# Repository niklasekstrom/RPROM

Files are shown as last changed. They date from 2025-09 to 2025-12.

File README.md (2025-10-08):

# RPROM

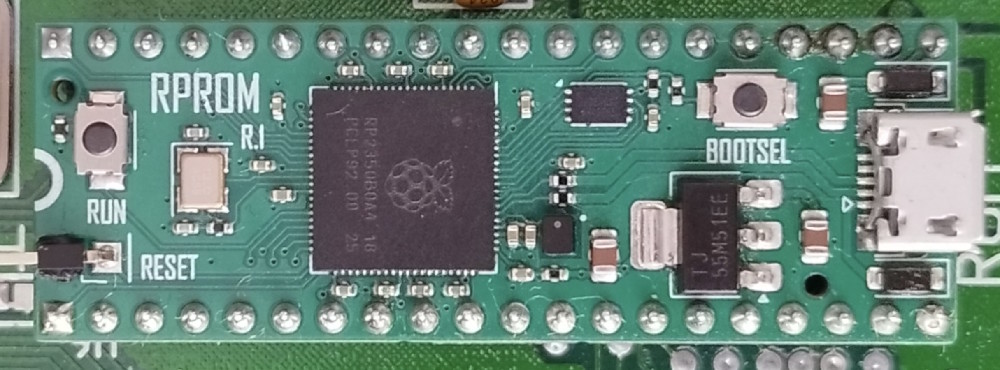
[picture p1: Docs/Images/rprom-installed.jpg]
RPROM rendered


RPROM is a ROM emulator for 16 bit Amiga computers (A500, A600, A2000) based on
the RP2350B microcontroller. RPROM was designed in collaboration by
[Niklas Ekström](https://github.com/niklasekstrom/) and
[Per Bengtsson](https://github.com/RetroNynjah).

The RPROM board has a 4 MB SPI flash memory. Each ROM image is 512 kB in size,
and therefore the 4 MB is divided into eight *slots* of 512 kB each. The first
slot is dedicated to store code and configuration data for the RP2350B. The
seven remaining slots are used to store ROM images.

ROM images can be written to flash memory either via USB, or directly from the
Amiga using a program called `RPROM`. This `RPROM` program is also used to
switch which slot is the *active slot*.

This repository contains the [hardware](Hardware), [firmware](Firmware) and
[software](Software) for RPROM. The design is intended to be easily
understandable and hackable. For example, the firmware is built from a single,
roughly 300 lines long, [source code file](Firmware/rprom.c).

## The RPROM command

`RPROM` is a CLI command that runs on the Amiga. It has the following
subcommands:

- `RPROM status` prints status information about the device
- `RPROM switch <slot>` switches the active slot and reboots the Amiga
- `RPROM write <slot> <image>` writes the content of file `<image>` to
slot `<slot>`
- `RPROM read <slot> <image>` reads the content of slot `<slot>` and saves it
to file `<image>`
- `RPROM erase <slot>` erases slot `<slot>`

Note that ROM images should *not* be byte swapped.

## Programming using USB

Both the firmware and ROM images can be programmed from a PC using USB.
Programming is done using the `picotool` program, which can be downloaded from
https://github.com/raspberrypi/pico-sdk-tools/releases. The RP2350B
microcontroller needs to first be in download mode. To put the RP2350B in
download mode, hold down the BOOTSEL button on the board, and then click the
RUN button. The microcontroller should show up as a USB drive on your PC.

To program the firmware, run `picotool load rprom.uf2`.

To write a ROM image to a slot, run `picotool load <image> -t bin -o <addr>`,
where `<addr>` depends on the slot:

- slot 1: `0x10080000`
- slot 2: `0x10100000`
- slot 3: `0x10180000`
- slot 4: `0x10200000`
- slot 5: `0x10280000`
- slot 6: `0x10300000`
- slot 7: `0x10380000`

## License

This design is free for non-comercial use. The designers take no responsibility
for if it doesn't work or if it causes damage to your equipment. If you want to
build boards to sell then you need to first ask for approval from the designers.

## Bill of materials (BOM)

| References | Value | Footprint | LCSC Part | Quantity |
|---|---|---|---|---|
| C2, C8, C11, C12, C13, C14, C15, C16, C17, C18, C20, C21 | 100n | C_0402_1005Metric | C1525 | 12 |
| C1, C5, C19 | 10u | C_0805_2012Metric | C15850 | 3 |
| C3, C4 | 15p | C_0402_1005Metric | C1548 | 2 |
| C6, C7, C9, C10 | 4.7u | C_0402_1005Metric | C23733 | 4 |
| R2, R4, R6 | 1k | R_0402_1005Metric | C11702 | 3 |
| R7, R8 | 27 | R_0402_1005Metric | C25092 | 2 |
| R1 | 10k | R_0402_1005Metric | C25744 | 1 |
| R3 | 33 | R_0402_1005Metric | C25105 | 1 |
| L1 | 3.3u | L_pol_2016 | C42411119 | 1 |
| D1, D2 | B5819W_SL | D_SOD-123 | C8598 | 2 |
| U1 | RP2350_80QFN | RP2350-QFN-80-1EP_10x10_P0.4mm_EP3.4x3.4mm | C42415655 | 1 |
| U2 | TLV1117-33 | SOT-223-3_TabPin2 | C15578 | 1 |
| Y1 | ABM8-272-T3 | Crystal_SMD_3225-4Pin_3.2x2.5mm | C20625731 | 1 |
| SW1, SW2 | SW_Push | SW_SPST_TS-1088 | C720477 | 2 |
| IC1 | W25Q32RVXHJQ *or* ZD25WQ32CEIGR | Winbond_USON-8-1EP_3x2mm_P0.5mm_EP0.2x1.6mm | C5258281 | 1 |
| J1 | USB_B_Micro | USB_Micro-B_Amphenol_10103594-0001LF_Horizontal | C428495 | 1 |
| J2, J3 | Conn_01x20 | PinHeader_1x20_P2.54mm_Vertical | - | 2 |
| J4 | Conn_01x01 | PinHeader_1x01_P2.54mm_Horizontal | - | 1 |

## Building

The hardware can be cheaply built by [JLCPCB](https://jlcpcb.com/) using
Economic PCBA. Components should be assembled only on the top side, and select
that tooling holes are "Added by Customer".

Please pay attention to the orientation of the components if ordering assembly
from JLCPCB. Especially pay attention to the orientation of coil L1. When
uploading the component placement file to JLCPCB I had to manually fix the
orientation of L1 regardless of what the component placement file specified.

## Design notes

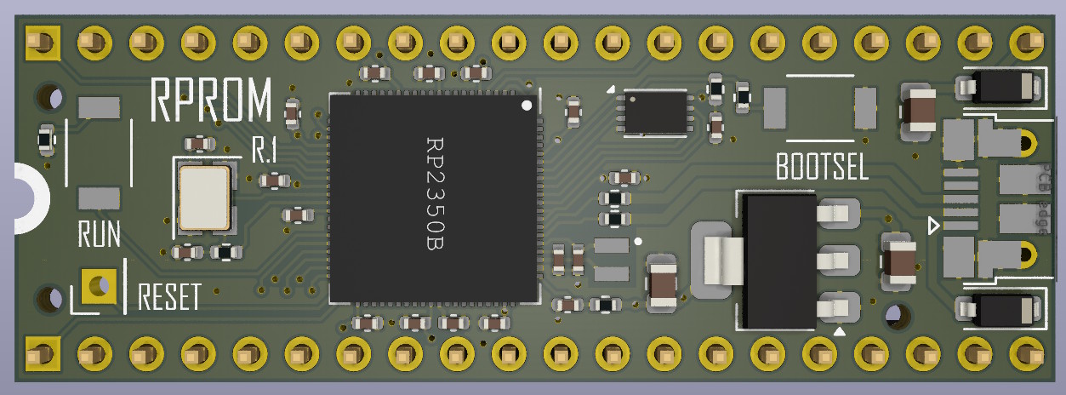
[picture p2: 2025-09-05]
Docs/Images/rprom-rendered.jpg

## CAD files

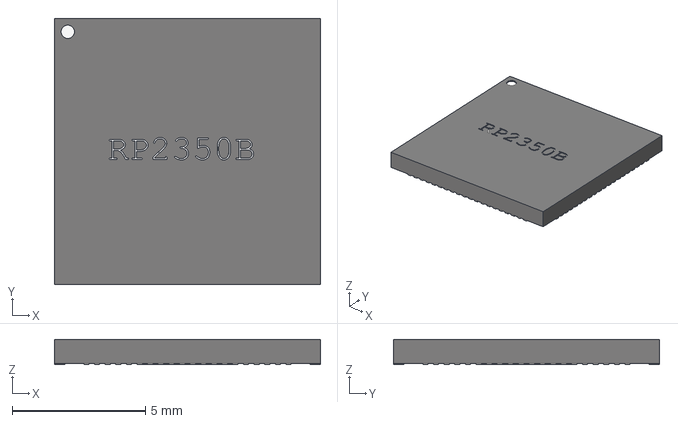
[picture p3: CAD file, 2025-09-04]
Hardware/KiCad/RP2350_QFN80.step
10.0 x 10.0 x 0.95 mm

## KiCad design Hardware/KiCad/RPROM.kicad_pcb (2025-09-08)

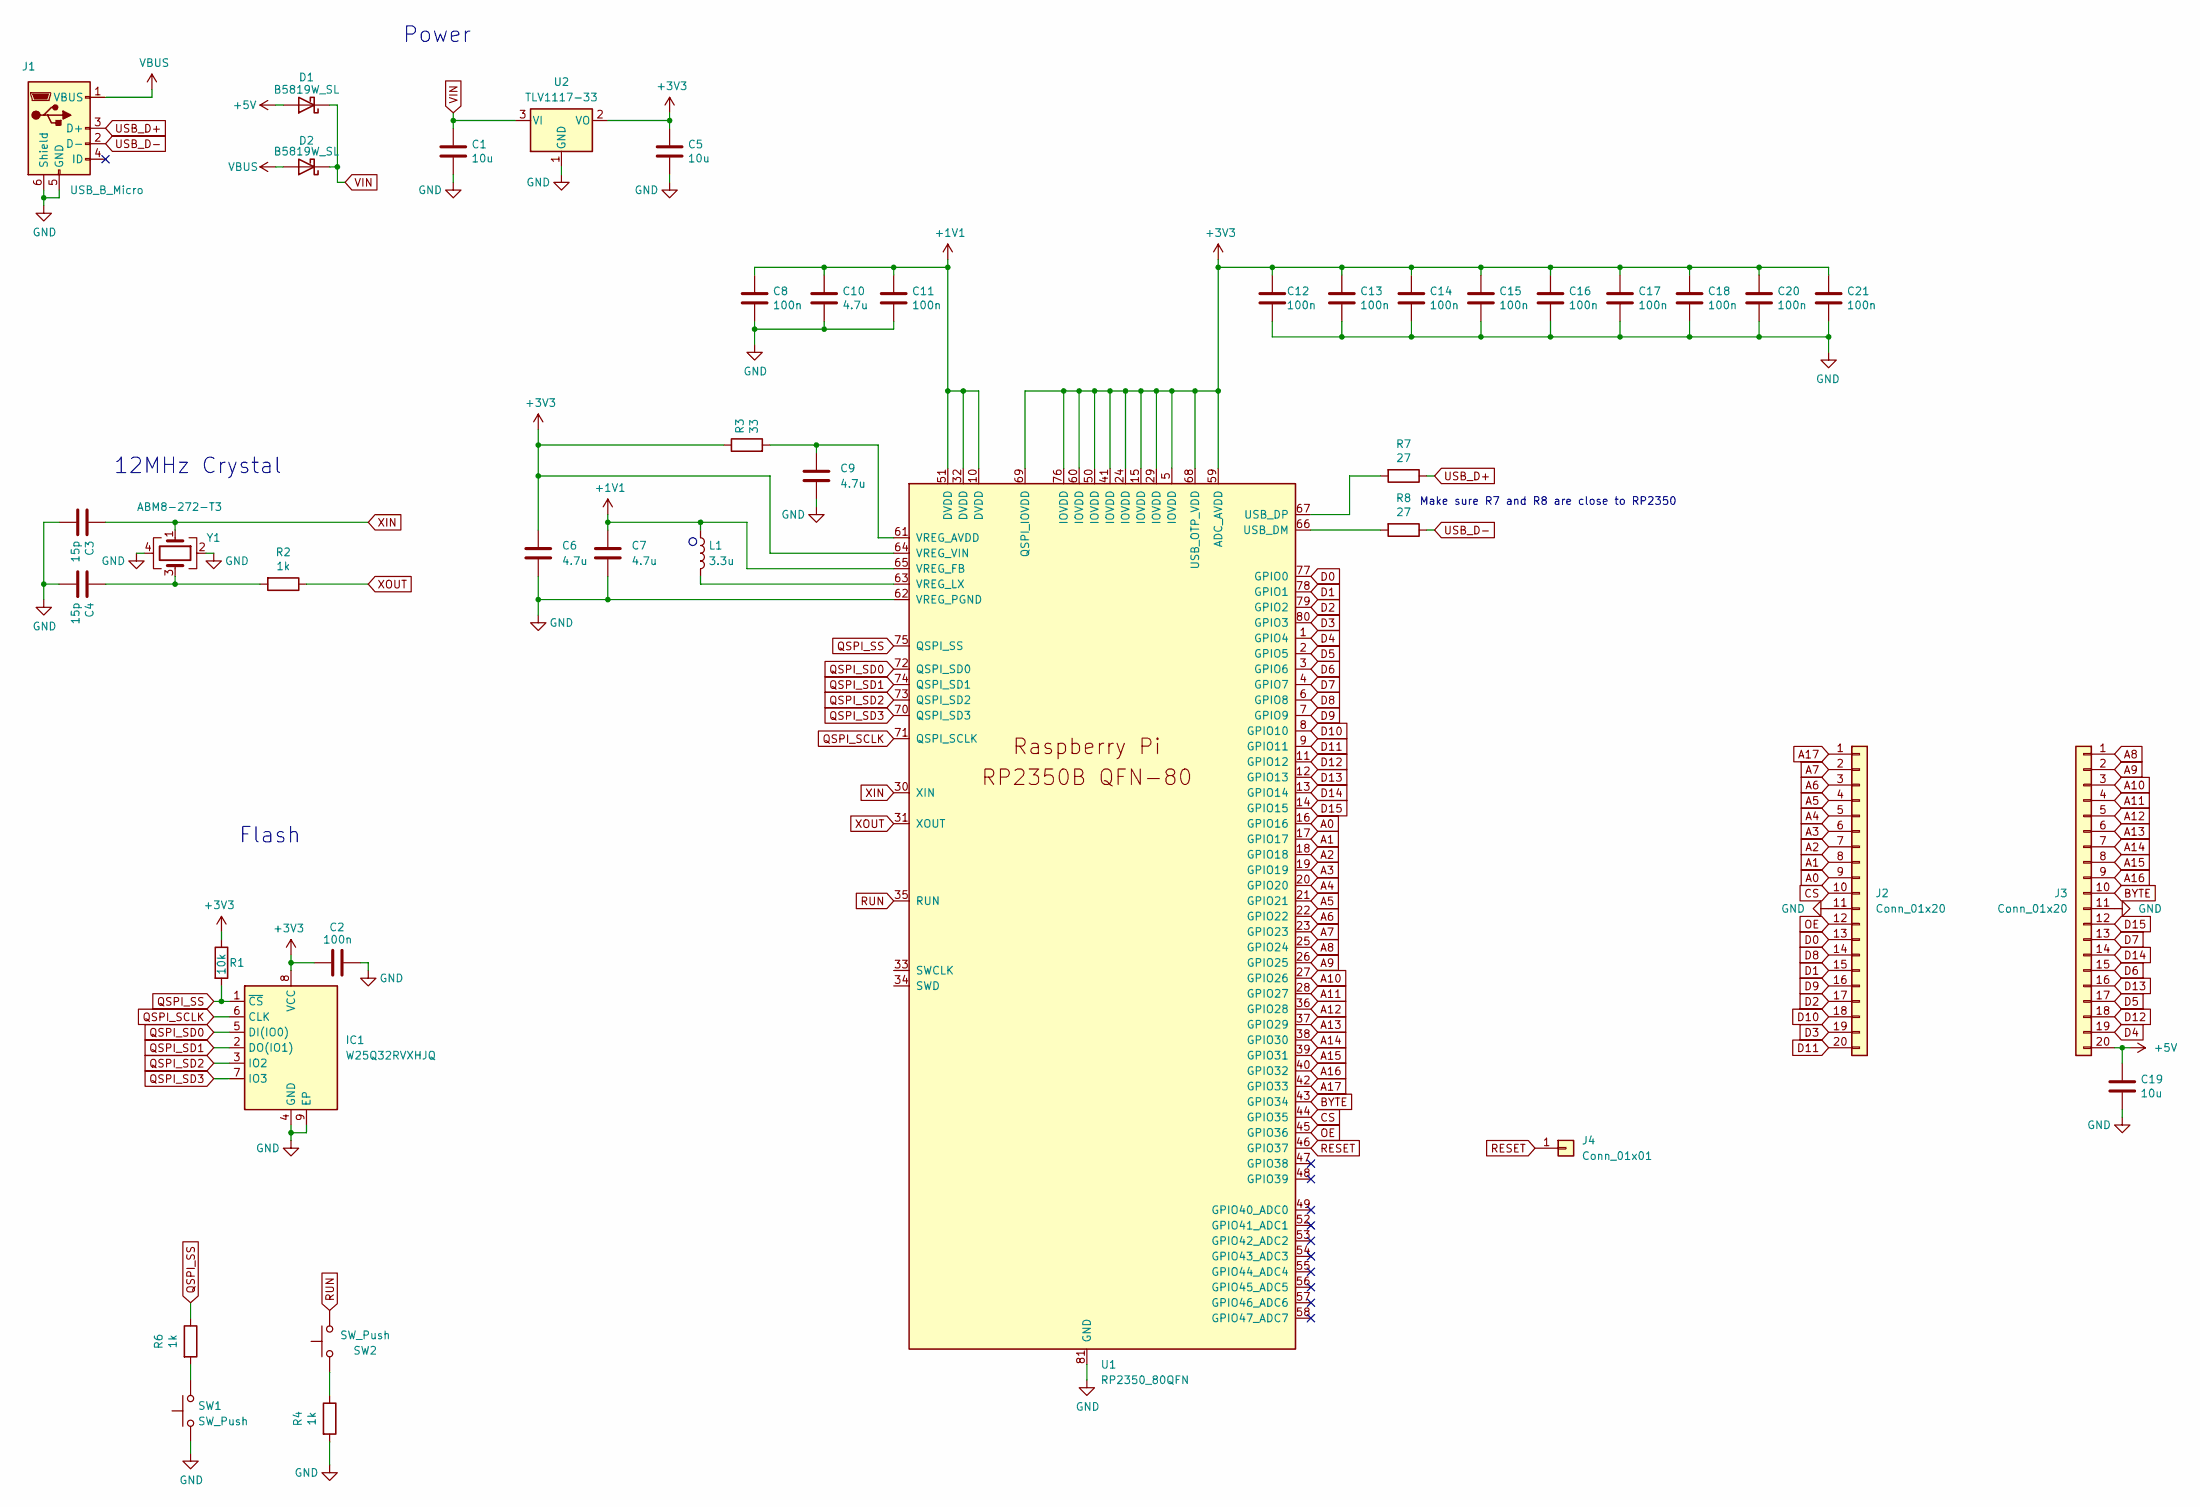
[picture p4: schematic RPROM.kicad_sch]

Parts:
C1, C5, C19: 10u; C_0805_2012Metric
C2, C8, C11, C12, C13, C14, C15, C16, C17, C18, C20, C21: 100n; C_0402_1005Metric
C3, C4: 15p; C_0402_1005Metric
C6, C7: 4.7u; C_0402_1005Metric_small_pads
C9, C10: 4.7u; C_0402_1005Metric
D1, D2: B5819W_SL; D_SOD-123
IC1: W25Q32RVXHJQ; Winbond_USON-8-1EP_3x2mm_P0.5mm_EP0.2x1.6mm
J1: USB_B_Micro; USB_Micro-B_Amphenol_10103594-0001LF_Horizontal
J2, J3: Conn_01x20; PinHeader_1x20_P2.54mm_Vertical
J4: Conn_01x01; PinHeader_1x01_P2.54mm_Vertical
L1: 3.3u; L_pol_2016
R1: 10k; R_0402_1005Metric
R2, R4, R6: 1k; R_0402_1005Metric
R3: 33; R_0402_1005Metric
R7, R8: 27; R_0402_1005Metric
SW1, SW2: SW_Push; SW_SPST_TS-1088
U1: RP2350_80QFN; RP2350-QFN-80-1EP_10x10_P0.4mm_EP3.4x3.4mm_ThermalVias
U2: TLV1117-33; SOT-223-3_TabPin2
Y1: ABM8-272-T3; Crystal_SMD_3225-4Pin_3.2x2.5mm

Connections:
+1V1: C7.1, C8.1, C10.1, C11.1, L1.1, U1.10 (DVDD), U1.32 (DVDD), U1.51 (DVDD), U1.65 (VREG_FB)
+3V3: C2.1, C5.1, C6.1, C12.1, C13.1, C14.1, C15.1, C16.1, C17.1, C18.1, C20.1, C21.1, IC1.8 (VCC), R1.1, R3.1, U1.5 (IOVDD), U1.15 (IOVDD), U1.24 (IOVDD), U1.29 (IOVDD), U1.41 (IOVDD), U1.50 (IOVDD), U1.59 (ADC_AVDD), U1.60 (IOVDD), U1.64 (VREG_VIN), U1.68 (USB_OTP_VDD), U1.69 (QSPI_IOVDD), U1.76 (IOVDD), U2.2 (VO)
+5V: C19.1, D1.2 (A), J3.20
A0: J2.9, U1.16 (GPIO16)
A1: J2.8, U1.17 (GPIO17)
A2: J2.7, U1.18 (GPIO18)
A3: J2.6, U1.19 (GPIO19)
A4: J2.5, U1.20 (GPIO20)
A5: J2.4, U1.21 (GPIO21)
A6: J2.3, U1.22 (GPIO22)
A7: J2.2, U1.23 (GPIO23)
A8: J3.1, U1.25 (GPIO24)
A9: J3.2, U1.26 (GPIO25)
A10: J3.3, U1.27 (GPIO26)
A11: J3.4, U1.28 (GPIO27)
A12: J3.5, U1.36 (GPIO28)
A13: J3.6, U1.37 (GPIO29)
A14: J3.7, U1.38 (GPIO30)
A15: J3.8, U1.39 (GPIO31)
A16: J3.9, U1.40 (GPIO32)
A17: J2.1, U1.42 (GPIO33)
BYTE: J3.10, U1.43 (GPIO34)
CS: J2.10, U1.44 (GPIO35)
D0: J2.13, U1.77 (GPIO0)
D1: J2.15, U1.78 (GPIO1)
D2: J2.17, U1.79 (GPIO2)
D3: J2.19, U1.80 (GPIO3)
D4: J3.19, U1.1 (GPIO4)
D5: J3.17, U1.2 (GPIO5)
D6: J3.15, U1.3 (GPIO6)
D7: J3.13, U1.4 (GPIO7)
D8: J2.14, U1.6 (GPIO8)
D9: J2.16, U1.7 (GPIO9)
D10: J2.18, U1.8 (GPIO10)
D11: J2.20, U1.9 (GPIO11)
D12: J3.18, U1.11 (GPIO12)
D13: J3.16, U1.12 (GPIO13)
D14: J3.14, U1.13 (GPIO14)
D15: J3.12, U1.14 (GPIO15)
GND: C1.2, C2.2, C3.2, C4.2, C5.2, C6.2, C7.2, C8.2, C9.2, C10.2, C11.2, C12.2, C13.2, C14.2, C15.2, C16.2, C17.2, C18.2, C19.2, C20.2, C21.2, IC1.4 (GND), IC1.9 (EP), J1.5 (GND), J1.6 (Shield), J2.11, J3.11, R4.2, SW1.1, U1.62 (VREG_PGND), U1.81 (GND), U2.1 (GND), Y1.2, Y1.4
unnamed: C4.1, R2.2, Y1.3
unnamed: R4.1, SW2.1
unnamed: R6.2, SW1.2
unnamed: R8.2, U1.66 (USB_DM)
unnamed: R7.2, U1.67 (USB_DP)
unnamed: C9.1, R3.2, U1.61 (VREG_AVDD)
unnamed: L1.2, U1.63 (VREG_LX)
OE: J2.12, U1.45 (GPIO36)
QSPI_SCLK: IC1.6 (CLK), U1.71 (QSPI_SCLK)
QSPI_SD0: IC1.5 (DI(IO0)), U1.72 (QSPI_SD0)
QSPI_SD1: IC1.2 (DO(IO1)), U1.74 (QSPI_SD1)
QSPI_SD2: IC1.3 (IO2), U1.73 (QSPI_SD2)
QSPI_SD3: IC1.7 (IO3), U1.70 (QSPI_SD3)
QSPI_SS: IC1.1 (~CS), R1.2, R6.1, U1.75 (QSPI_SS)
RESET: J4.1, U1.46 (GPIO37)
RUN: SW2.2, U1.35 (RUN)
USB_D+: J1.3 (D+), R7.1
USB_D-: J1.2 (D-), R8.1
VBUS: D2.2 (A), J1.1 (VBUS)
VIN: C1.1, D1.1 (K), D2.1 (K), U2.3 (VI)
XIN: C3.1, U1.30 (XIN), Y1.1
XOUT: R2.1, U1.31 (XOUT)

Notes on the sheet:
12MHz Crystal
Make sure R7 and R8 are close to RP2350
Flash
Power

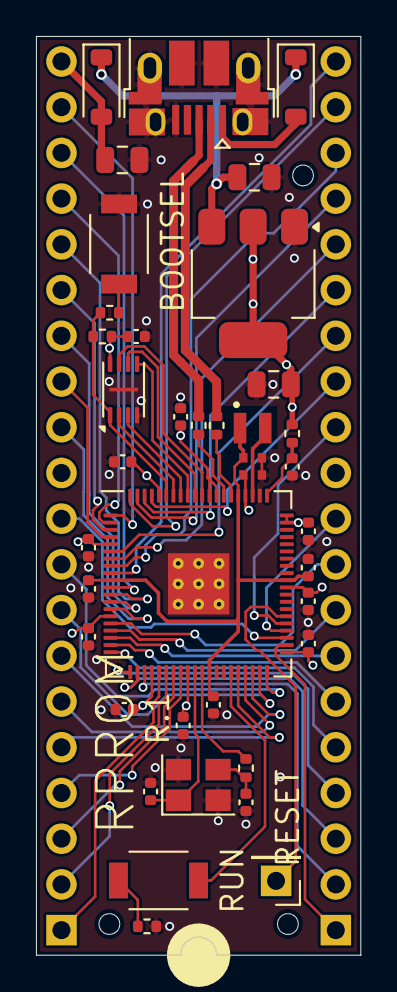
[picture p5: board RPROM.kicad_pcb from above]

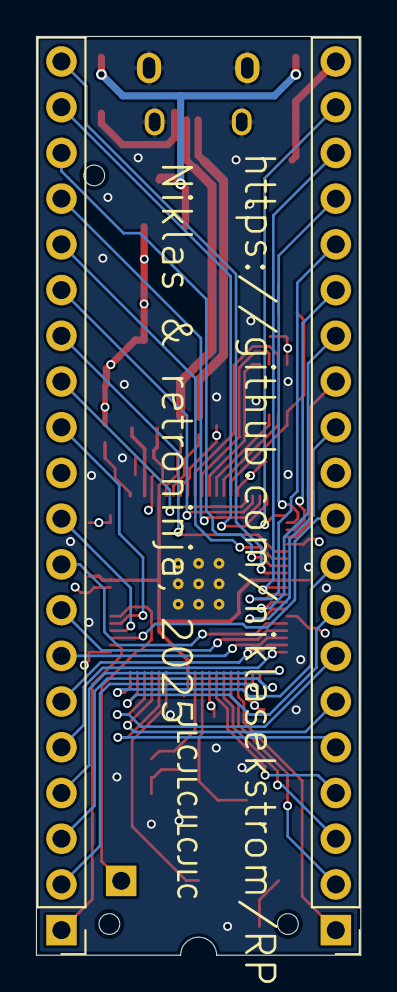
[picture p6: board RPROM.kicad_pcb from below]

Board: 4 copper layers, 18.0 x 51.0 mm, 41 parts (2 on the bottom side), 62 nets.

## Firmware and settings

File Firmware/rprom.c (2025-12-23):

/*
 * RPROM firmware
 *
 * Copyright (C) 2025 Niklas Ekström
 */
#include "hardware/clocks.h"
#include "hardware/flash.h"
#include "hardware/gpio.h"

#include "pico/flash.h"
#include "pico/multicore.h"

#include <string.h>

#include "protocol.h"

// Pins 0..15 are 16 bit data bus
// Pins 16..33 are 18 bit address bus
#define BYTE_PIN    34
#define CE_PIN      35
#define OE_PIN      36
#define RESET_PIN   37

#define DATA_MASK ((1 << 16) - 1)
#define ADDR_MASK ((1 << 18) - 1)

#define MAJOR_VERSION 1
#define MINOR_VERSION 0
#define PATCH_VERSION 1

#define ROM_SLOT_SIZE (512 * 1024)

__attribute__((section(".rom_image")))
static uint16_t rom_image[ROM_SLOT_SIZE / 2];

#define CONFIG_SECTOR_OFFSET    (ROM_SLOT_SIZE - FLASH_SECTOR_SIZE)
#define CONFIG_SECTOR_BASE      (XIP_BASE + CONFIG_SECTOR_OFFSET)

struct ConfigTuple
{
    uint32_t rom_slot;
    uint32_t reserved;
};

struct ConfigPage
{
    uint32_t pages_bitmap;
    uint32_t tuples_bitmap;
    struct ConfigTuple tuples[31];
};

static inline uint32_t get_active_rom_slot()
{
    struct ConfigPage *pages = (struct ConfigPage *)CONFIG_SECTOR_BASE;
    uint32_t active_page = __builtin_ctz(pages[0].pages_bitmap);
    uint32_t active_tuple = __builtin_ctz(pages[active_page].tuples_bitmap);
    uint32_t rom_slot = pages[active_page].tuples[active_tuple].rom_slot;
    return (rom_slot == 0 || rom_slot >= 8) ? 1 : rom_slot;
}

static void update_active_rom_slot_in_flash(uint32_t rom_slot)
{
    struct ConfigPage *pages = (struct ConfigPage *)CONFIG_SECTOR_BASE;
    uint32_t active_page = __builtin_ctz(pages[0].pages_bitmap);
    uint32_t active_tuple = __builtin_ctz(pages[active_page].tuples_bitmap);

    active_tuple++;
    if (active_tuple >= 31)
    {
        active_tuple = 0;
        active_page++;
        if (active_page >= 16)
        {
            active_page = 0;
            flash_range_erase(CONFIG_SECTOR_OFFSET, FLASH_SECTOR_SIZE);
        }
    }

    // Uses 256 bytes of stack space.
    struct ConfigPage page;
    memcpy(&page, (const void *)&pages[active_page], sizeof(page));

    page.pages_bitmap = ~((1 << active_page) - 1);
    page.tuples_bitmap = ~((1 << active_tuple) - 1);
    page.tuples[active_tuple].rom_slot = rom_slot;

    flash_range_program(CONFIG_SECTOR_OFFSET + active_page * FLASH_PAGE_SIZE,
                        (const uint8_t *)&page, FLASH_PAGE_SIZE);

    if (active_page != 0)
    {
        memcpy(&page, (const void *)&pages[0], FLASH_PAGE_SIZE);
        page.pages_bitmap = ~((1 << active_page) - 1);
        flash_range_program(CONFIG_SECTOR_OFFSET, (const uint8_t *)&page, FLASH_PAGE_SIZE);
    }
}

static void handle_magic_read(uint32_t address)
{
    uint32_t cmd = address >> 14;
    uint32_t arg = address & ((1 << 14) - 1);

    switch (cmd)
    {
        case CMD_UPDATE_ACTIVE_ROM_SLOT:
        {
            uint32_t rom_slot = arg;
            if (rom_slot == 0 || rom_slot > 7)
                return;

            update_active_rom_slot_in_flash(rom_slot);

            uint32_t rom_slot_base = XIP_BASE + rom_slot * ROM_SLOT_SIZE;
            memcpy(rom_image, (const void *)rom_slot_base, sizeof(rom_image));
            break;
        }
        case CMD_WRITE_STATUS_TO_SRAM:
        {
            struct StatusV1 *status = (struct StatusV1 *)rom_image;
            *status = (struct StatusV1) {
                .magic = STATUS_V1_MAGIC,
                .status_length = sizeof(struct StatusV1),
                .major_version = MAJOR_VERSION,
                .minor_version = MINOR_VERSION,
                .patch_version = PATCH_VERSION,
                .flash_size_mb = 4,
                .active_rom_slot = (uint8_t)get_active_rom_slot(),
            };
            break;
        }
        case CMD_RESTORE_PAGE_TO_SRAM:
        {
            const uint32_t rom_slot = get_active_rom_slot();
            const uint32_t rom_slot_base = XIP_BASE + rom_slot * ROM_SLOT_SIZE;
            memcpy(rom_image, (const void *)rom_slot_base, FLASH_PAGE_SIZE + 2);
            break;
        }
        case CMD_COPY_PAGE_AMIGA_TO_SRAM:
        {
            for (int i = 0; i < 128; i++)
                rom_image[i] = __builtin_bswap16((uint16_t)multicore_fifo_pop_blocking_inline());

            break;
        }
        case CMD_COPY_PAGE_FLASH_TO_SRAM:
        {
            rom_image[128] = 0xffff;
            memcpy(rom_image, (const void *)(XIP_BASE + arg * FLASH_PAGE_SIZE), FLASH_PAGE_SIZE);
            rom_image[128] = 0;
            break;
        }
        case CMD_COPY_PAGE_SRAM_TO_FLASH:
        {
            rom_image[128] = 0xffff;
            flash_range_program(arg * FLASH_PAGE_SIZE, (const uint8_t *)rom_image, FLASH_PAGE_SIZE);
            rom_image[128] = 0;
            break;
        }
        case CMD_ERASE_FLASH_SECTOR:
        {
            rom_image[128] = 0xffff;
            flash_range_erase(arg * FLASH_SECTOR_SIZE, FLASH_SECTOR_SIZE);
            rom_image[128] = 0;
            break;
        }
    }
}

static void __not_in_flash_func(core1_main)()
{
    uint32_t magic_counter = 0;

    while (1)
    {
        uint32_t address = multicore_fifo_pop_blocking_inline();

        if (magic_counter == 0)
        {
            if (address == MAGIC_ADDR_0)
                magic_counter++;
        }
        else if (magic_counter == 1)
        {
            if (address == MAGIC_ADDR_1)
                magic_counter++;
            else
                magic_counter = 0;
        }
        else if (magic_counter == 2)
        {
            if (address == MAGIC_ADDR_2)
                magic_counter++;
            else
                magic_counter = 0;
        }
        else
        {
            handle_magic_read(address);
            magic_counter = 0;
        }
    }
}

static inline void multicore_fifo_push_non_blocking_inline(uint32_t data) {
    sio_hw->fifo_wr = data;
    __sev();
}

static void __not_in_flash_func(core0_main)(bool rev6)
{
    while (1)
    {
        uint64_t all_pins = gpio_get_all64();

        if ((all_pins & (1ULL << OE_PIN)) == 0)
        {
            uint32_t address;
            if (rev6)
            {
                address = (all_pins >> 16) & ADDR_MASK;
            }
            else
            {
                address = (all_pins >> 16) & ((1 << 17) - 1);
                address |= (all_pins >> (BYTE_PIN - 17)) & (1 << 17);
            }

            uint32_t value = (uint32_t)__builtin_bswap16(rom_image[address]);

            gpio_put_masked(DATA_MASK, value);
            gpio_set_dir_out_masked(DATA_MASK);

            multicore_fifo_push_non_blocking_inline(address);

            while (gpio_get(OE_PIN) == 0)
            {
                tight_loop_contents();
            }

            gpio_set_dir_in_masked(DATA_MASK);
        }
    }
}
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

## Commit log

2025-08-16 Move switch to core1
2025-08-17 Add slot config to flash
2025-09-01 Make write command automatically erase slot first
2025-09-04 Add hardware rev 1
    [RP2350_QFN80.step, RPROM.kicad_pcb, RPROM.kicad_sch]
2025-09-05 Add missing fclose calls
    [rprom.c]
2025-09-06 Reboot by software after switching
    [rprom.c]
2025-09-08 Update KiCad design to use correct flash component
    [RPROM.kicad_pcb, RPROM.kicad_sch]
2025-09-09 Add bill of materials (BOM) to readme
2025-10-02 Set PICO_HEAP_SIZE to zero
    The firmware on the RP2350B isn't doing dynamic memory allocations
    (malloc/free), so there is no need to set aside memory for a heap.
    Removing the heap prohibits printf debugging over USB.
2025-10-08 Add paragraph about economic pcba to README
2025-12-23 Fix typo to mask out the lower 14 bits
    By chance the typo didn't cause an actual problem even though the
    masking was incorrect.
    Reported by Nico Bendlin
    [rprom.c]
2026-04-12 Add reset pin handling for switching active slot
